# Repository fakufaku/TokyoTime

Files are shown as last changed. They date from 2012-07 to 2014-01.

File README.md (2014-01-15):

## TokyoTime

An arduino based alarm-clock. But much more than that. It has a Two-Wire interface, serial interface, RTC, temperature sensor and a buzzer.

These features make it ideal for all projects where temperature and time are critical like:

  * Waking up in the morning,
  * Cooking,
  * Brewing,
  * Making yogurt,
  * etc.

In addition it can be powered from a CR2032 battery, or from a 5V wall-wart.

This project builds on the [BigTime](https://github.com/nseidle/BigTime) project by @nseidle, but the whole board was redesigned from scratch.



## Assembly

Checkout the assembly guide [here](https://dl.dropbox.com/u/78009186/Documents/TokyoTime_2.1_assembly.pdf).

## Bootloader

The bootloader needed is the "Atmega328 on a breadboard" bootloader available
(with instructions) from the Arduino
[website](http://arduino.cc/en/Tutorial/ArduinoToBreadboard).

The bootloader add-on files for Arduino IDE are located in `firmware/hardware`.
To install them, simply copy the `firmware/hardware` to the local Arduino
folder.

The TokyoTime doesn't have an ISP header to upload the firmware, so another
board must be used to burn the bootloader to the chip. A standard Arduino board
can be used.

The fuse should be set automatically when burning the bootloader using Arduino IDE.
If not, the fuse should be set to use the internal 8MHz oscillator and disable
the brown-out threshold. The fuse can be burnt with avrdude using the following
command

    -U lfuse:w:0xe2:m -U hfuse:w:0xda:m -U efuse:w:0x07:m

## Firmware

The TokyoTime board features a handy serial header that can be used to upload
new code to the chip (provided it has a bootloader) with a 3.3V FTDI-to-USB converter
such as this [one](https://www.sparkfun.com/products/9873).

There are so far three different firmware for the board.

* **TokyoTime** `firmware/TokyoTime` -- A standard clock with settable alarm
  and temperature reading. 
* **Kuishimbo** `firmware/Kuishimbo` -- A controller using a PID loop to
  control the temperature of a toaster oven. There is a blog
  [post](http://robinscheibler.org/hacks/2012/08/21/fixing-an-electric-oven/)
  describing the whole project.  This firmware requires the Arduino PID library
  located in `firmware/libraries`. It can be copied to the local Arduino.
* **TokyoIncubator** `firmware/TokyoIncubator` -- A controller using a PID loop
  to control the temperature of an incubator for bacteria, yoghurt or natto
  culture. This was later spun into a
  [project](https://github.com/BioDesignRealWorld/Fermento) of its
  [own](http://biodesign.cc/2013/12/25/diy-incubator/). This firmware requires the
  Arduino PID library located in `firmware/libraries`. It can be copied to the
  local Arduino.

## Bill Of Material

All the parts can be bought at [Akizuki Denshi](http://www.akizukidenshi.com/)
in Akihabara, Tokyo. Equivalent parts can be found on
[Mouser](http://www.mouser.com), but please check the datasheets to make sure
the footprints correspond.

* 1x Green 7 segment (common cathode) [OSL40562-LG](http://akizukidenshi.com/catalog/g/gI-03945/)
* 1x 3.3V Regulator [TA48M033F](http://akizukidenshi.com/catalog/g/gI-00538/)
* 1x [Atmega328p](http://akizukidenshi.com/catalog/g/gI-03142/)
* 1x [28-pin socket]() (optional, allows to change chip easily)
* 1x [Buzzer](http://akizukidenshi.com/catalog/g/gP-04118/) (13mm)
* 1x [Tactil switch](http://akizukidenshi.com/catalog/g/gP-03651/)
* 1x Temperature sensor [LM61CIZ](http://akizukidenshi.com/catalog/g/gI-02726/)
* 1x [32.768 Crystal](http://akizukidenshi.com/catalog/g/gP-04005/)
* 1x [2.1mm barrel jack](http://akizukidenshi.com/catalog/g/gC-00077/)
* 1x [2032 coin cell holder](http://akizukidenshi.com/catalog/g/gP-00706/)
* 4x [0.1uF cap](http://akizukidenshi.com/catalog/g/gP-00090/) (C1, C2, C3, C5) (one 0.1uF cap is included with regulator from Akizuki)
* 1x 47uF cap (C4) (Also included with regulator from Akizuki, value may vary)
* 2x 10K resistors (R1, R3)
* 1K resistor (R2)
* 1x6 pin header
* 1x3 pin header
* 3x2 pin header

## License

(c) 2011-2014, Robin Scheibler

This work is realeased under the [CC-BY-SA 3.0](http://creativecommons.org/licenses/by-sa/3.0/us/) License.

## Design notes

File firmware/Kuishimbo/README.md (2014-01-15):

### Kuishimbo

(c) Fakufaku 2012, Beerware license

>
> _Kuishimbo_ : Japanese for 'Glutton'
> 

This is the firmware for the [TokyoTime](http://github.com/fakufaku/TokyoTime) board used to control my baking oven.

It uses the Arduino [PID library](http://arduino.cc/playground/Code/PIDLibrary).

There's a [blog post](http://fakufaku.github.com/hacks/2012/08/21/fixing-an-electric-oven/) describing the hacking of the oven.

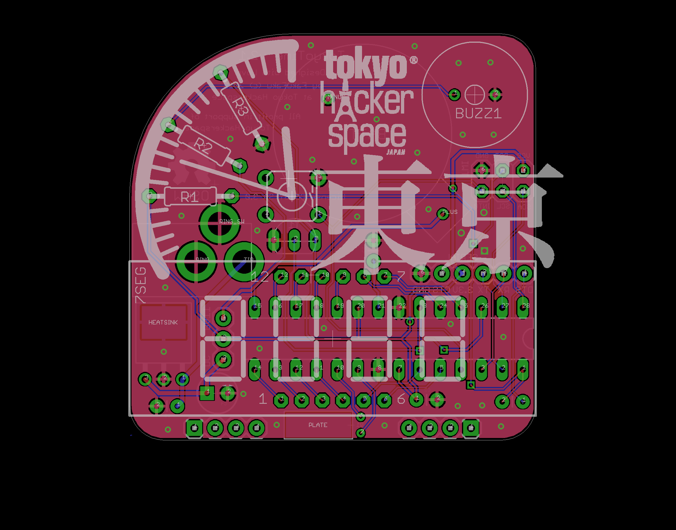
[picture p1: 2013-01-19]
TokyoTime_brd.png

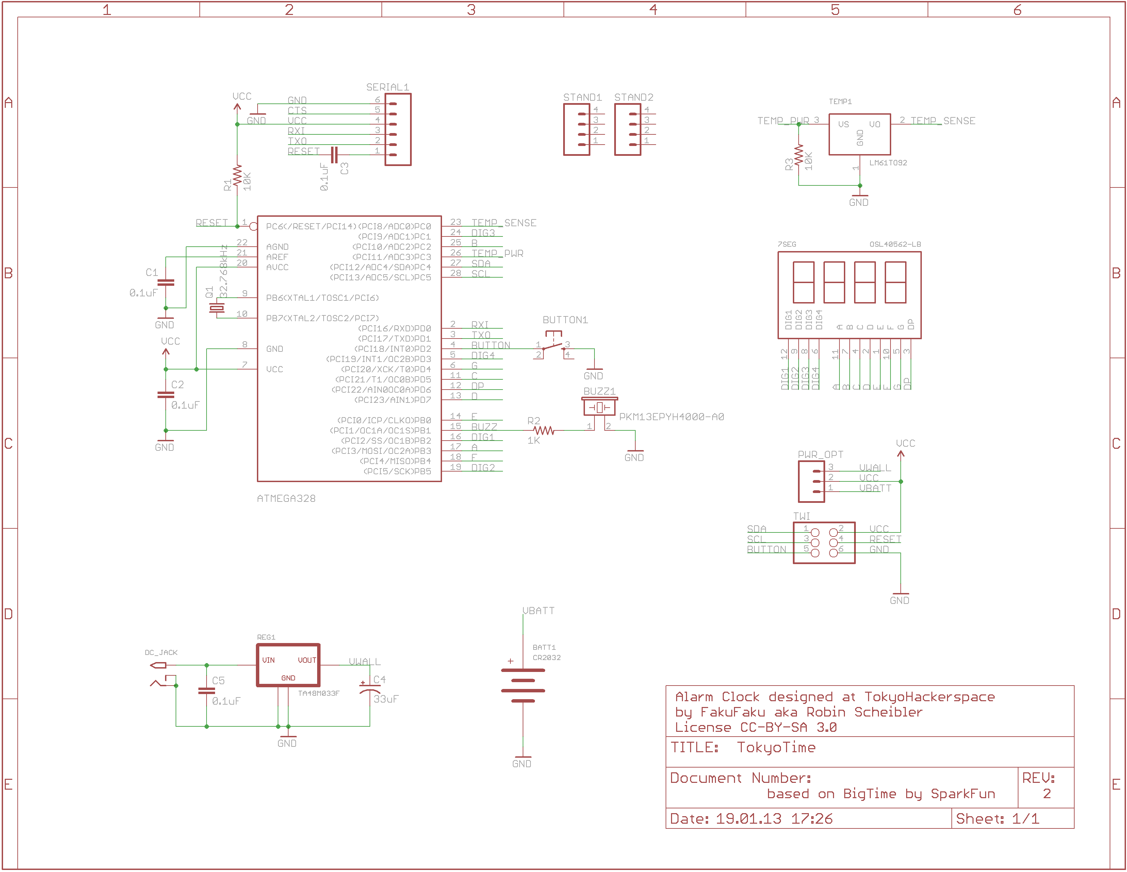
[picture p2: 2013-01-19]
TokyoTime_sch.png

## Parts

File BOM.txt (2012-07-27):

Partlist

Exported from TokyoTime.sch at 27.07.12 09:10

EAGLE Version 5.11.0 Copyright (c) 1988-2010 CadSoft

Part      Value            Device         Package              Library  Sheet

7SEG      OSL40562-LB      7SEG           OSL40562             Robin    1
ATMEGA328                  ATMEGA168-20P  DIL28-3              adafruit 1
BATT1     CR2032           BATTERY-HOLDER CR2032-HOLDER-20MM   Robin    1
BUTTON1                    TAC_SWITCHPTH  TACTILE-PTH          SparkFun 1
BUZZ1     PKM13EPYH4000-A0 BUZZER13MM     PIEZO-MURATA-13MM    Robin    1
C1        0.1uF            CAPPTH         CAP-PTH-SMALL        SparkFun 1
C2        0.1uF            CAPPTH         CAP-PTH-SMALL        SparkFun 1
C3        0.1uF            CAPPTH         CAP-PTH-SMALL        SparkFun 1
C4        33uF             CAP_POLPTH2    CPOL-RADIAL-10UF-25V SparkFun 1
C5        0.1uF            CAPPTH         CAP-PTH-SMALL        SparkFun 1
DC_JACK   2.1MMJACKTHM     2.1MMJACKTHM   PJ-102A              adafruit 1
PWR_OPT                    M03PTH         1X03                 SparkFun 1
Q1        32.768kHz        CRYSTAL8X3     CRYSTAL-8X3-TH       Robin    1
R1        10K              R-US_0207/10   0207/10              adafruit 1
R2        1K               R-US_0207/10   0207/10              adafruit 1
R3        10K              R-US_0207/10   0207/10              adafruit 1
REG1      TA48M033F        REGULATOR      HSIP3-P-2.30B        Robin    1
SERIAL1                    M06SIP         1X06                 SparkFun 1
STAND1                     M04PTH         1X04                 SparkFun 1
STAND2                     M04PTH         1X04                 SparkFun 1
TEMP1     LM61TO92         LM61TO92       TO92-                Robin    1
TWI                        PINHD-2X3      2X03                 pinhead  1

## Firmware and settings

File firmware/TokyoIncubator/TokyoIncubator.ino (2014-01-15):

/*
 * (c) Fakufaku 2014
 * This is the code I use to control an oven I hacked.
 * This code is released under the beerware license, i.e. if you use it, and it is useful, pay me beer, maybe.
 * The part of the code that's used for the display on the 7-segment was ripped off the BigTime code from Nathan Seidl. I owe him a beer then.
 */

#include <math.h>

#include <PID_v1.h>

#define TRUE 1
#define FALSE 0

//Careful messing with the system color, you can damage the display if
//you assign the wrong color. If you're in doubt, set it to red and load the code,
//then see what the color is.
#define RED  1
#define GREEN 2
#define BLUE  3
#define YELLOW  4
int systemColor = GREEN;
int display_brightness = 8000; //A larger number makes the display more dim. This is set correctly below.

//-=-=-=-=-=-=-=-=-=-=-=-=-=-=-=-=-=-=
//Pin definitions
int digit1 = 10;    //Display pin 12
int digit2 = 13;    //Display pin 9
int digit3 = A1;    //Display pin 8
int digit4 = 3;     //Display pin 6

int segA = 11;      //Display pin 11
int segB = A2;      //Display pin 7
int segC = 5;       //Display pin 4
int segD = 7;       //Display pin 2
int segE = 8;       //Display pin 1
int segF = 12;      //Display pin 10
int segG = 4;       //Display pin 5

int colons = 6;     //Display pin 3

//Set this variable to change how long the time is shown on the watch face. In milliseconds so 1677 = 1.677 seconds
int show_time_length = 2000;

int temp_pwr = A3;  // to power the temperature sensor
int temp_sen = A0;  // to read the temperature sensor

const static int temp_out = A0;
const static int temp_out_pwr = A3;

const static int buzz = 9;
const static int theButton = 2;

unsigned long timer = 0;

// slow continuous PWM variables
#define PWM_MS 5000
#define PWM_MIN 250
#define RELAY_ON HIGH
#define RELAY_OFF LOW
unsigned long windowStartTime;
const static int pwm_pin = A5;  // SCL, brown wire

// control variables for PID
double t_incub;      // input to PID
double t_incub_N;    // number of samples in t_incub average
double pwm_duty;    // output of PID
double t_set = 0; // set point

// oven max temperature
#define MAX_TEMP 50
#define TEMP_INCREMENT 1
#define MAX_TIME (24*60*60)
#define TIME_INCREMENT 60

//Specify the links and initial tuning parameters
double kp=50,ki=0.3
,kd=1;
PID myPID(&t_incub, &pwm_duty, &t_set, kp, ki, kd, DIRECT);

// display timer (freeze parameters to display for 2 seconds)
int t_incub_disp;

// Timer variables
unsigned long timer_seconds = 0;

//The very important 32.768 interrupt handler
SIGNAL(TIMER2_OVF_vect)
{
  if (timer_seconds > 1)
  {
    timer_seconds--;
  }
  else if (timer_seconds == 1)
  {
    // reset timer
    timer_seconds = 0;
    // turn off by setting target temperature to zero
    t_set = 0;
    // Reset the PID
    myPID.SetMode(MANUAL);
    myPID.SetMode(AUTOMATIC);
  }
}

void setup()
{
  //Serial.begin(57600);

  // set ADC reference to 3.3V
  analogReference(DEFAULT);

  // initialize temperature sensor and turn on
  pinMode(temp_out_pwr, OUTPUT);
  digitalWrite(temp_out_pwr, HIGH);

  // initialize pwm drive pin, and turn it off
  pinMode(pwm_pin, OUTPUT);
  digitalWrite(pwm_pin, HIGH);

  // initialize buzzer pin
  pinMode(buzz, OUTPUT);

  // initialize the button
  pinMode(theButton, INPUT);
  digitalWrite(theButton, HIGH); // pull-up

  //Setup TIMER2
  TCCR2A = 0x00;
  TCCR2B = (1<<CS22)|(1<<CS20); //Set CLK/128 or overflow interrupt every 1s
  ASSR   = (1<<AS2); //Enable asynchronous operation
  TIMSK2 = (1<<TOIE2); //Enable the timer 2 interrupt

  //These pins are used to control the display
  pinMode(segA, OUTPUT);
  pinMode(segB, OUTPUT);
  pinMode(segC, OUTPUT);
  pinMode(segD, OUTPUT);
  pinMode(segE, OUTPUT);
  pinMode(segF, OUTPUT);
  pinMode(segG, OUTPUT);

  pinMode(digit1, OUTPUT);
  pinMode(digit2, OUTPUT);
  pinMode(digit3, OUTPUT);
  pinMode(digit4, OUTPUT);
  pinMode(colons, OUTPUT);

  // setup PID stuff
  myPID.SetOutputLimits(PWM_MIN-1, PWM_MS-PWM_MIN+1);
  myPID.SetMode(AUTOMATIC);
  myPID.SetSampleTime(PWM_MS);
  windowStartTime = millis();

  // initialize pwm
  pwm_duty = 0; // off
  t_incub = read_temperature();
  t_incub_N = 1;

  // initialize slow variables for display
  t_incub_disp = t_incub;

}

void loop()
{
  
  temperatureControl();

  // display and output to serial
  displayTemperature((int)(t_incub_disp), FALSE); //Each call takes about 8ms, display the colon

  if (digitalRead(theButton) == LOW)
  {
    // set temperature first
    setTemperature();
    // then time
    setTime();
  }

}

// Simple PWM based on millis directly
void temperatureControl()
{

  unsigned long now = millis();

  t_incub += (read_temperature() - t_incub)/(++t_incub_N);

  if(now - windowStartTime > PWM_MS)
  { 
    // compute new pwm value for that window
    myPID.Compute();

    // start a new relay window
    windowStartTime = now;

    // restart averaging of oven temperature
    t_incub_disp = t_incub;
    t_incub = read_temperature();
    t_incub_N = 1;

  }

  // if t_set is zero, that means oven is off
  if (t_set < 1)
  {
    pwm_duty = 0;
  }

  if (pwm_duty < PWM_MIN)
  {
    digitalWrite(pwm_pin, RELAY_OFF);
  }
  else if (pwm_duty < PWM_MS-PWM_MIN)
  {
    if(pwm_duty > now - windowStartTime) 
      digitalWrite(pwm_pin, RELAY_ON);
    else 
      digitalWrite(pwm_pin, RELAY_OFF);
  }
  else
  {
    digitalWrite(pwm_pin, RELAY_ON);
  }
}

float read_temperature()
{
  float A = 0;
  for (int i=0 ; i < 10 ; i++)
    A += analogRead(temp_out);
  A /= 10;
  return (A/1023.*3300 - 600)/10;
}

//This routine occurs when you hold the button down
//The colon blinks indicating we are in this mode
//Holding the button down will increase the time (accelerates)
//Releasing the button for more than 2 seconds will exit this mode
void setTemperature()
{

  int idleMiliseconds = 0;
  //This is the timeout counter. Once we get to ~2 seconds of inactivity, the watch
  //will exit the setTime function and return to normal operation

  while(idleMiliseconds < 2000) {

    for(int x = 0 ; x < 7 ; x++) {
      displayTemperature(t_set, TRUE); //Each call takes about 8ms, display the colon for about 100ms
      delayMicroseconds(display_brightness); //Wait before we paint the display again
    }
    for(int x = 0 ; x < 7 ; x++) {
      displayTemperature(t_set, FALSE); //Each call takes about 8ms, turn off the colon for about 100ms
      delayMicroseconds(display_brightness); //Wait before we paint the display again
    }

    //If you're still hitting the button, then increase the time and reset the idleMili timeout variable
    if(digitalRead(theButton) == LOW) {
      idleMiliseconds = 0;

      t_set = ((int)(t_set+TEMP_INCREMENT) % MAX_TEMP); // Increase temperature
    }

    idleMiliseconds += 200;
  }
}

//This routine occurs when you hold the button 2 down
//The colon blinks indicating we are in this mode
//Holding the button down will increase the time (accelerates)
//Releasing the button for more than 2 seconds will exit this mode
void setTime()
{
  int idleMiliseconds = 0;
  //This is the timeout counter. Once we get to ~2 seconds of inactivity, the watch
  //will exit the setTime function and return to normal operation

  while(idleMiliseconds < 2000) 
  {

    int timer_disp = (timer_seconds/3600)*100 + (timer_seconds/60)%60 
      + (timer_seconds % 60 == 0 ? 0 : 1);

    for(int x = 0 ; x < 10 ; x++) {
      displayTime(timer_disp, TRUE); //Each call takes about 8ms, display the colon for about 100ms
      delayMicroseconds(display_brightness); //Wait before we paint the display again
    }
    for(int x = 0 ; x < 10 ; x++) {
      displayTime(timer_disp, FALSE); //Each call takes about 8ms, turn off the colon for about 100ms
      delayMicroseconds(display_brightness); //Wait before we paint the display again
    }

    //If you're still hitting the button, then increase the time and reset the idleMili timeout variable
    if(digitalRead(theButton) == LOW) {
      idleMiliseconds = 0;

      timer_seconds = ((int)(timer_seconds+TIME_INCREMENT) % MAX_TIME); // Increase timer
    }

    idleMiliseconds += 200;
  }
}


/************************************/
/* Routines to display on 7-segment */
/************************************/

//Given 102, we display "102.°"
//Each digit is displayed for ~2000us, and cycles through the 4 digits
//After running through the 4 numbers, the display is turned off
void displayTemperature(int toDisplay, boolean displayColon)
{

#define DIGIT_ON   LOW
#define DIGIT_OFF  HIGH

  for(int digit = 4 ; digit > 0 ; digit--) {

    //Turn on a digit for a short amount of time
    switch(digit) {
    case 1:
      digitalWrite(digit1, DIGIT_ON);
      digitalWrite(colons, LOW);
      break;
    case 2:
      digitalWrite(digit2, DIGIT_ON);
      digitalWrite(colons, LOW);
      break;
    case 3:
      digitalWrite(digit3, DIGIT_ON);
      if(displayColon == TRUE) 
        digitalWrite(colons, HIGH); //When we update digit 2, let's turn on colons as well
      else
        digitalWrite(colons, LOW);
      break;
    case 4:
      digitalWrite(digit4, DIGIT_ON);
      digitalWrite(colons, LOW);
      break;
    }

    //Now display this digit
    if (digit != 4)
    {
      if( (toDisplay/10 != 0) || (toDisplay % 10) != 0) // do not display leading zeros
        lightNumber(toDisplay % 10); //Turn on the right segments for this digit

      toDisplay /= 10;
    }
    else
    {
      lightNumber('º');
    }

    delayMicroseconds(2000); //Display this digit for a fraction of a second (between 1us and 5000us, 500-2000 is pretty good)
    //If you set this too long, the display will start to flicker. Set it to 25000 for some fun.

    //Turn off all segments
    lightNumber(10);

    //Turn off all digits
    digitalWrite(digit1, DIGIT_OFF);
    digitalWrite(digit2, DIGIT_OFF);
    digitalWrite(digit3, DIGIT_OFF);
    digitalWrite(digit4, DIGIT_OFF);
    digitalWrite(colons, DIGIT_OFF);
  }

}
//Given 1022, we display "10.22"
//Each digit is displayed for ~2000us, and cycles through the 4 digits
//After running through the 4 numbers, the display is turned off
void displayTime(int toDisplay, boolean displayColon)
{

#define DIGIT_ON   LOW
#define DIGIT_OFF  HIGH

  for(int digit = 4 ; digit > 0 ; digit--) {

    //Turn on a digit for a short amount of time
    switch(digit) {
    case 1:
      digitalWrite(digit1, DIGIT_ON);
      digitalWrite(colons, LOW);
      break;
    case 2:
      digitalWrite(digit2, DIGIT_ON);
      if(displayColon == TRUE) 
        digitalWrite(colons, HIGH); //When we update digit 2, let's turn on colons as well
      else
        digitalWrite(colons, LOW);
      break;
    case 3:
      digitalWrite(digit3, DIGIT_ON);
      digitalWrite(colons, LOW);
      break;
    case 4:
      digitalWrite(digit4, DIGIT_ON);
      digitalWrite(colons, LOW);
      break;
    }

    //Now display this digit
    lightNumber(toDisplay % 10); //Turn on the right segments for this digit

    toDisplay /= 10;

    delayMicroseconds(2000); //Display this digit for a fraction of a second (between 1us and 5000us, 500-2000 is pretty good)
    //If you set this too long, the display will start to flicker. Set it to 25000 for some fun.

    //Turn off all segments
    lightNumber(10);

    //Turn off all digits
    digitalWrite(digit1, DIGIT_OFF);
    digitalWrite(digit2, DIGIT_OFF);
    digitalWrite(digit3, DIGIT_OFF);
    digitalWrite(digit4, DIGIT_OFF);
    digitalWrite(colons, DIGIT_OFF);
    //digitalWrite(ampm, DIGIT_OFF);
  }

}

//Takes a string like "gren" and displays it, left justified
//We don't use the colons, or AMPM dot, so they are turned off
void displayLetters(char *colorName)
{
#define DIGIT_ON  HIGH
#define DIGIT_OFF  LOW

  digitalWrite(digit4, DIGIT_OFF);
  digitalWrite(colons, DIGIT_OFF);
  //digitalWrite(ampm, DIGIT_OFF);

  for(int digit = 0 ; digit < 4 ; digit++) {
    //Turn on a digit for a short amount of time
    switch(digit) {
    case 0:
      digitalWrite(digit1, DIGIT_ON);
      break;
    case 1:
      digitalWrite(digit2, DIGIT_ON);
      break;
    case 2:
      digitalWrite(digit3, DIGIT_ON);
      break;
    case 3:
      digitalWrite(digit4, DIGIT_ON);
      break;
    }

    //Now display this letter
    lightNumber(colorName[digit]); //Turn on the right segments for this letter

    delayMicroseconds(2000); //Display this digit for a fraction of a second (between 1us and 5000us, 500-2000 is pretty good)
    //If you set this too long, the display will start to flicker. Set it to 25000 for some fun.

    //Turn off all segments
    lightNumber(10);

    //Turn off all digits
    digitalWrite(digit1, DIGIT_OFF);
    digitalWrite(digit2, DIGIT_OFF);
    digitalWrite(digit3, DIGIT_OFF);
  }
}

//Given a number, turns on those segments
//If number == 10, then turn off all segments
void lightNumber(int numberToDisplay)
{

#define SEGMENT_ON  HIGH
#define SEGMENT_OFF LOW

  /*
Segments
   -  A
   F / / B
   -  G
   E / / C
   -  D
   */

  switch (numberToDisplay)
  {

  case 0:
    digitalWrite(segA, SEGMENT_ON);
    digitalWrite(segB, SEGMENT_ON);
    digitalWrite(segC, SEGMENT_ON);
    digitalWrite(segD, SEGMENT_ON);
    digitalWrite(segE, SEGMENT_ON);
    digitalWrite(segF, SEGMENT_ON);
    break;

  case 1:
    digitalWrite(segB, SEGMENT_ON);
    digitalWrite(segC, SEGMENT_ON);
    break;

  case 2:
    digitalWrite(segA, SEGMENT_ON);
    digitalWrite(segB, SEGMENT_ON);
    digitalWrite(segD, SEGMENT_ON);
    digitalWrite(segE, SEGMENT_ON);
    digitalWrite(segG, SEGMENT_ON);
    break;

  case 3:
    digitalWrite(segA, SEGMENT_ON);
    digitalWrite(segB, SEGMENT_ON);
    digitalWrite(segC, SEGMENT_ON);
    digitalWrite(segD, SEGMENT_ON);
    digitalWrite(segG, SEGMENT_ON);
    break;

  case 4:
    digitalWrite(segB, SEGMENT_ON);
    digitalWrite(segC, SEGMENT_ON);
    digitalWrite(segF, SEGMENT_ON);
    digitalWrite(segG, SEGMENT_ON);
    break;

  case 5:
    digitalWrite(segA, SEGMENT_ON);
    digitalWrite(segC, SEGMENT_ON);
    digitalWrite(segD, SEGMENT_ON);
    digitalWrite(segF, SEGMENT_ON);
    digitalWrite(segG, SEGMENT_ON);
    break;

  case 6:
    digitalWrite(segA, SEGMENT_ON);
    digitalWrite(segC, SEGMENT_ON);
    digitalWrite(segD, SEGMENT_ON);
    digitalWrite(segE, SEGMENT_ON);
    digitalWrite(segF, SEGMENT_ON);
    digitalWrite(segG, SEGMENT_ON);
    break;

  case 7:
    digitalWrite(segA, SEGMENT_ON);
    digitalWrite(segB, SEGMENT_ON);
    digitalWrite(segC, SEGMENT_ON);
    break;

  case 8:
    digitalWrite(segA, SEGMENT_ON);
    digitalWrite(segB, SEGMENT_ON);
    digitalWrite(segC, SEGMENT_ON);
    digitalWrite(segD, SEGMENT_ON);
    digitalWrite(segE, SEGMENT_ON);
    digitalWrite(segF, SEGMENT_ON);
    digitalWrite(segG, SEGMENT_ON);
    break;

  case 9:
    digitalWrite(segA, SEGMENT_ON);
    digitalWrite(segB, SEGMENT_ON);
    digitalWrite(segC, SEGMENT_ON);
    digitalWrite(segD, SEGMENT_ON);
    digitalWrite(segF, SEGMENT_ON);
    digitalWrite(segG, SEGMENT_ON);
    break;

  case 10:
    digitalWrite(segA, SEGMENT_OFF);
    digitalWrite(segB, SEGMENT_OFF);
    digitalWrite(segC, SEGMENT_OFF);
    digitalWrite(segD, SEGMENT_OFF);
    digitalWrite(segE, SEGMENT_OFF);
    digitalWrite(segF, SEGMENT_OFF);
    digitalWrite(segG, SEGMENT_OFF);
    break;

    /*
Segments
     -  A
     F / / B
     -    G
     E / / C
     - D
     */

    //Letters
  case 'b': //cdefg
    digitalWrite(segC, SEGMENT_ON);
    digitalWrite(segD, SEGMENT_ON);
    digitalWrite(segE, SEGMENT_ON);
    digitalWrite(segF, SEGMENT_ON);
    digitalWrite(segG, SEGMENT_ON);
    break;
  case 'L': //def
    digitalWrite(segD, SEGMENT_ON);
    digitalWrite(segE, SEGMENT_ON);
    digitalWrite(segF, SEGMENT_ON);
    break;
  case 'u': //cde
    digitalWrite(segC, SEGMENT_ON);
    digitalWrite(segD, SEGMENT_ON);
    digitalWrite(segE, SEGMENT_ON);
    break;

  case 'g': //abcdfg
    digitalWrite(segA, SEGMENT_ON);
    digitalWrite(segB, SEGMENT_ON);
    digitalWrite(segC, SEGMENT_ON);
    digitalWrite(segD, SEGMENT_ON);
    digitalWrite(segF, SEGMENT_ON);
    digitalWrite(segG, SEGMENT_ON);
    break;
  case 'r': //eg
    digitalWrite(segE, SEGMENT_ON);
    digitalWrite(segG, SEGMENT_ON);
    break;
  case 'n': //ceg
    digitalWrite(segC, SEGMENT_ON);
    digitalWrite(segE, SEGMENT_ON);
    digitalWrite(segG, SEGMENT_ON);
    break;

    //case r
  case 'e': //adefg
    digitalWrite(segA, SEGMENT_ON);
    digitalWrite(segD, SEGMENT_ON);
    digitalWrite(segE, SEGMENT_ON);
    digitalWrite(segF, SEGMENT_ON);
    digitalWrite(segG, SEGMENT_ON);
    break;
  case 'd': //bcdeg
    digitalWrite(segB, SEGMENT_ON);
    digitalWrite(segC, SEGMENT_ON);
    digitalWrite(segD, SEGMENT_ON);
    digitalWrite(segE, SEGMENT_ON);
    digitalWrite(segG, SEGMENT_ON);
    break;
  case ' ': //None
    digitalWrite(segA, SEGMENT_OFF);
    digitalWrite(segB, SEGMENT_OFF);
    digitalWrite(segC, SEGMENT_OFF);
    digitalWrite(segD, SEGMENT_OFF);
    digitalWrite(segE, SEGMENT_OFF);
    digitalWrite(segF, SEGMENT_OFF);
    digitalWrite(segG, SEGMENT_OFF);
    break;

  case 'y': //bcdfg
    digitalWrite(segB, SEGMENT_ON);
    digitalWrite(segC, SEGMENT_ON);
    digitalWrite(segD, SEGMENT_ON);
    digitalWrite(segF, SEGMENT_ON);
    digitalWrite(segG, SEGMENT_ON);
    break;
    //case e 
    //case L
  case 'o': //cdeg
    digitalWrite(segC, SEGMENT_ON);
    digitalWrite(segD, SEGMENT_ON);
    digitalWrite(segE, SEGMENT_ON);
    digitalWrite(segG, SEGMENT_ON);
    break;

  case 'º': // abfg
    digitalWrite(segA, SEGMENT_ON);
    digitalWrite(segB, SEGMENT_ON);
    digitalWrite(segF, SEGMENT_ON);
    digitalWrite(segG, SEGMENT_ON);
    break;

  }
}

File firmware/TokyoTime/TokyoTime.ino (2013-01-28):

/*
 7-17-2011
 Spark Fun Electronics 2011
 Nathan Seidle
 
 This code is public domain but you buy me a beer if you use this and we meet someday (Beerware license).
 
 This is the firmware for BigTime, the wrist watch kit. It is based on an ATmega328 running with internal
 8MHz clock and external 32kHz crystal for keeping the time (aka RTC). The code and system have been tweaked
 to lower the power consumption of the ATmeg328 as much as possible. The watch currently uses about 
 1.2uA in idle (non-display) mode and about 13mA when displaying the time. With a 200mAh regular 
 CR2032 battery you should get 2-3 years of use!
 
 To compile and load this code onto your watch, select "Arduino Pro or Pro Mini 3.3V/8MHz w/ ATmega328" from
 the Boards menu. 
 
 If you're looking to save power in your own project, be sure to read section 9.10 of the ATmega328 
 datasheet to turn off all the bits of hardware you don't need.
 
 BigTime requires the Pro 8MHz bootloader with a few modifications:
 Internal 8MHz
 Clock div 8 cleared
 Brown out detect disabled
 BOOTRST set
 BOOSZ = 1024 
 This is to save power and open up the XTAL pins for use with a 38.786kHz external osc.
 
 So the fuse bits I get using AVR studio:
 HIGH 0xDA
 LOW 0xE2
 Extended 0xFF  
 
 3,600 seconds in an hour
 1 time check per hour, 2 seconds at 13mA
 3,598 seconds @ 1.2uA
 (3598 / 3600) * 0.0012mA + (2 / 3600) * 13mA = 0.0084mA used per hour
 
 200mAh / 0.0084mA = 23,809hr = 992 days = 2.7 years
 
 We can't use the standard Arduino delay() or delaymicrosecond() because we shut down timer0 to save power
 
 We turn off Brown out detect because it alone uses ~16uA.
 
 7-2-2011: Currently at 1.13uA
 
 7-4-2011: Let's wake up every 8 seconds instead of every 1 to save even more power
 Since we don't display seconds, this should be fine
 We are now at ~1.05uA on average
 
 7-17-2011: 1.09uA, portable with coincell power
 Jumps to 1.47uA every 8 seconds with system clock lowered to 1MHz
 Jumps to 1.37uA every 8 seconds with system clock at 8MHz
 Let's keep the internal clock at 8MHz since it doesn't seem to help to lower the internal clock.
 
 8-11-2011: Adding display color so that production can more easily know what code is on the 
 pre-programmed ATmega. 
 
 8-19-2011: Now we can print things like "red, gren, blue, yelo".
 
 */

#include <avr/sleep.h> //Needed for sleep_mode
#include <avr/power.h> //Needed for powering down perihperals such as the ADC/TWI and Timers
#include <limits.h>

#define TRUE 1
#define FALSE 0

#define ALARM_ENABLE 1

//Set the 12hourMode to false for military/world time. Set it to true for American 12 hour time.
int TwelveHourMode = FALSE;

//Set this variable to change how long the time is shown on the watch face. In milliseconds so 1677 = 1.677 seconds
int show_time_length = 700;
int show_temp_length = 2000;
int show_color_length = 2000;
int show_the_temp = FALSE;

// Here show_the_time is a counter that conatins number of
// times the time should be show for a duration of show_time_length.
// So in total, time will be displayed for show_the_time x show_the_length ms.
int show_the_time = 0;  // number of time length time to display Time
int show_time_n = 7;

//You can set always_on to true and the display will stay on all the time
//This will drain the battery in about 15 hours 
int always_on = FALSE;

long seconds = 55;
int minutes = 12;
int hours = 8;

// The alarm parameters
int alarm_hours = 8;     // set to -1 to disable alarm
int alarm_minutes = 14;   // set to -1 to disable alarm
int alarm_on = FALSE;
int buzzing = FALSE;
int buzz_timer;
int buzz_seconds;
int buzz_snoozed = FALSE;

// now we need a push counter to offer more functionalities
int push_counter = 0;

//Careful messing with the system color, you can damage the display if
//you assign the wrong color. If you're in doubt, set it to red and load the code,
//then see what the color is.
#define RED  1
#define GREEN 2
#define BLUE  3
#define YELLOW  4
int systemColor = GREEN;
int display_brightness = 15000; //A larger number makes the display more dim. This is set correctly below.

//-=-=-=-=-=-=-=-=-=-=-=-=-=-=-=-=-=-=
//Pin definitions
int digit1 = 10;    //Display pin 12
int digit2 = 13;    //Display pin 9
int digit3 = A1;    //Display pin 8
int digit4 = 3;     //Display pin 6

int segA = 11;      //Display pin 11
int segB = A2;      //Display pin 7
int segC = 5;       //Display pin 4
int segD = 7;       //Display pin 2
int segE = 8;       //Display pin 1
int segF = 12;      //Display pin 10
int segG = 4;       //Display pin 5

int colons = 6;     //Display pin 3

int temp_pwr = A3;  // to power the temperature sensor
int temp_sen = A0;  // to read the temperature sensor

int buzzer = 9;      // the buzzer to wake you up

int theButton = 2;
//-=-=-=-=-=-=-=-=-=-=-=-=-=-=-=-=-=-=

// Temperature parameters
#define ANALOG_REF INTERNAL
#define VOLTAGE_REF 1077
#define temp_sense_on() digitalWrite(temp_pwr, HIGH);
#define temp_sense_off() digitalWrite(temp_pwr, LOW);
#define TEMP_MAX  60
#define TEMP_MIN -60

//The very important 32.686kHz interrupt handler
SIGNAL(TIMER2_OVF_vect)
{
  seconds += 8; //We sleep for 8 seconds instead of 1 to save more power
  //seconds++; //Use this if we are waking up every second

  //Update the minutes and hours variables
  minutes += seconds / 60; //Example: seconds = 2317, minutes = 58 + 38 = 96
  seconds %= 60; //seconds = 37
  hours += minutes / 60; //12 + (96 / 60) = 13
  minutes %= 60; //minutes = 36

  //Do we display 12 hour or 24 hour time?
  if(TwelveHourMode == TRUE) {
    //In 12 hour mode, hours go from 12 to 1 to 12.
    while(hours > 12) hours -= 12;
  }
  else {
    //In 24 hour mode, hours go from 0 to 23 to 0.
    while(hours > 23) hours -= 24;
  }
}

//The interrupt occurs when you push the button
SIGNAL(INT0_vect)
{
  if (show_the_time > 0 || always_on == TRUE)
    show_the_temp = TRUE; // if the clock is already on, then show temperature instead

  //When you hit the button, we will need to display the time
  show_the_time = show_time_n;

  // turn buzzer off (in case alarm is ringing)
  if (buzzing)
    buzz_snoozed = TRUE;
  // increase the push counter
  push_counter++;
}
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

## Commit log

2012-01-26 First commit. Board auto-routed.
    [TokyoTime.brd, TokyoTime.sch]
2012-01-26 Now passing DRC with no errors.
    [TokyoTime.brd, TokyoTime.sch]
2012-01-27 Added png images
    [TokyoTime.brd]
2012-01-27 Added BOM (export from eagle).
2012-01-30 Did final manual routing. Added some of the art.
    [TokyoTime.brd, TokyoTime.sch]
2012-01-30 PNGs of schematics and board layout.
2012-01-30 Connected interrupt to TWI pin header.
    [TokyoTime.sch]
2012-01-30 Finished laying out the board, with art! No errors at DRC (fusion PCB).
    [TokyoTime.brd]
2012-01-30 Updated BOM
2012-01-30 Moved 7seg name so that it doesn't overlap with art.
    [TokyoTime.brd]
2012-01-30 Added board name and version on the back.
    [TokyoTime.brd]
2012-01-31 Added Akizuki reference links to BOM.
2012-02-06 Modified Crystal trace to fit Akizuki's crystal. Changed stand to 1x4 pin headers.
    [TokyoTime.brd, TokyoTime.sch]
2012-03-29 Added arduino sketch.
2012-07-19 Corrected TWI connector pin mislabeling bug. Corrected LM61 TO92 incorrect footprint.
    [TokyoTime.brd, TokyoTime.sch]
2012-07-27 Moved battery holder and TWI header to leave some room for the serial cable.
    [TokyoTime.brd, TokyoTime.sch]
2013-01-19 Disconnect AREF pin from VCC. Move some silk screen labels that were hidden under a connector.
    [TokyoTime.brd, TokyoTime.sch]
2013-01-19 New version of the TokyoTime sketch. Now temperature displays correctly. Runs on internal ADC reference. No alarm yet.
2013-01-19 Modified the circuit to have a decoupling cap on AREF. Now there is a single decoupling cap for both VCC and AVCC of ATmega328p.
    [TokyoTime.brd, TokyoTime.sch]
2013-01-19 The sketch has now been completed with the code for the alarm clock! Buzzer problem, solved. The ADC reference when using the battery problem remains. Now using AVCC ref.
2013-01-24 Modified the sketch so that we can sleep the LCD and save batteries (run on battery is meaningful).
2013-01-24 Renamed arduino sketch with .ino suffix.
2013-01-25 Added correct fuse settings to README.
2013-01-28 Modified readme with fuses to disable brownout. Modified sketch to disable ADC most of the time. Got current down to 1uA in sleep.
    [TokyoTime.ino]
2014-01-15 Added bootloader and PID library.
